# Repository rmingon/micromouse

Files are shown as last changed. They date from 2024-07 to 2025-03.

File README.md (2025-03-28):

# MICRO MOUSE Project

ir test (https://www.youtube.com/watch?v=sAMVhm9rnp0)

roll test (https://www.youtube.com/watch?v=oE-b8426ebo)

### 3d view

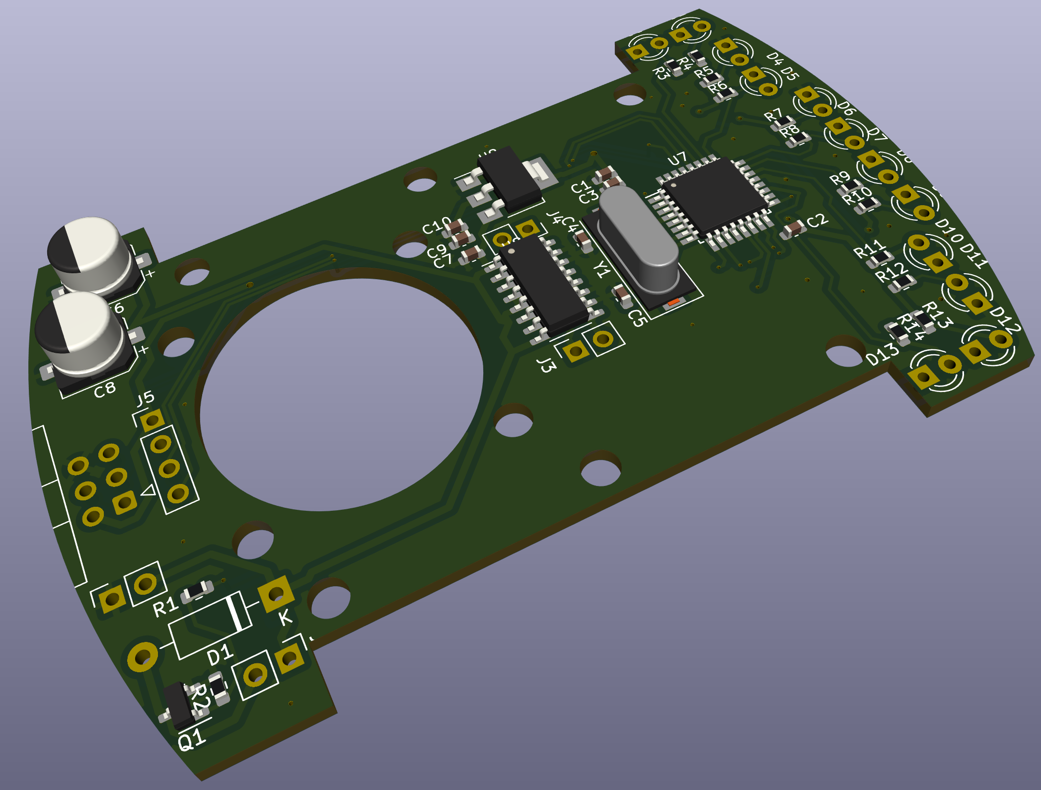
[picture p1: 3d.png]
'3d'


### pcb view

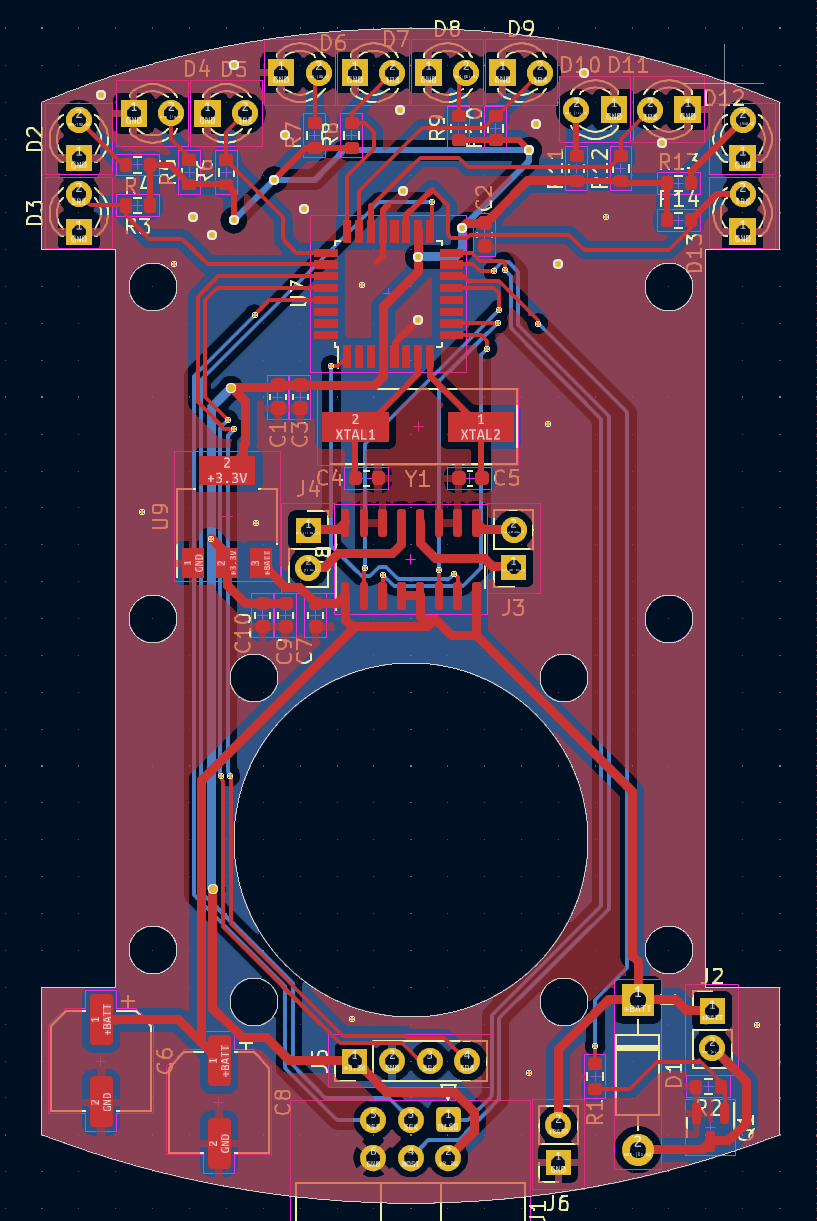
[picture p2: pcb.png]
'pcb'


### schematic view

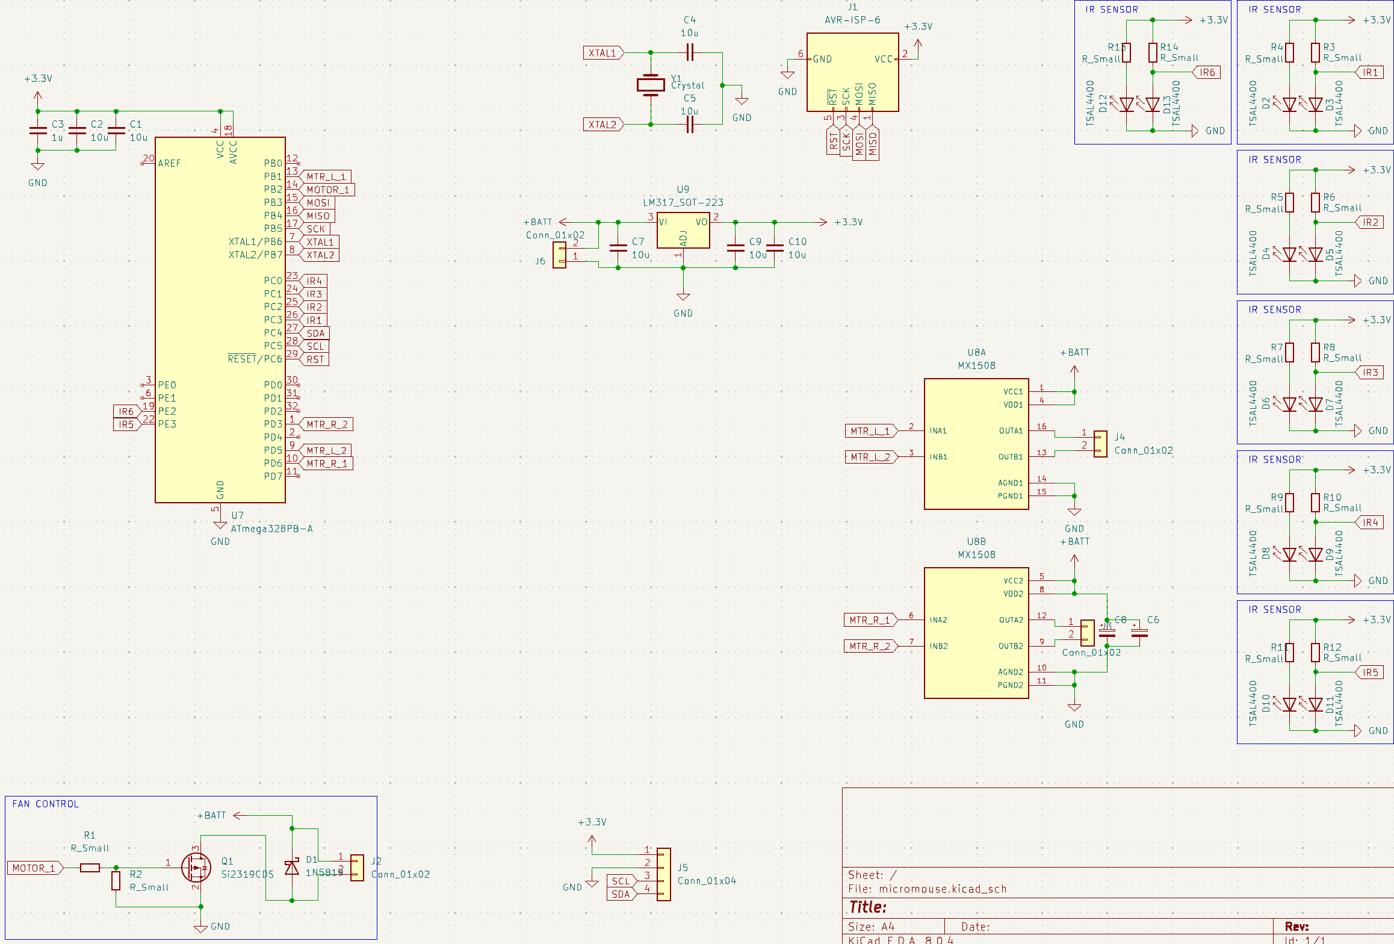
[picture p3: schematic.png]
'schematic'


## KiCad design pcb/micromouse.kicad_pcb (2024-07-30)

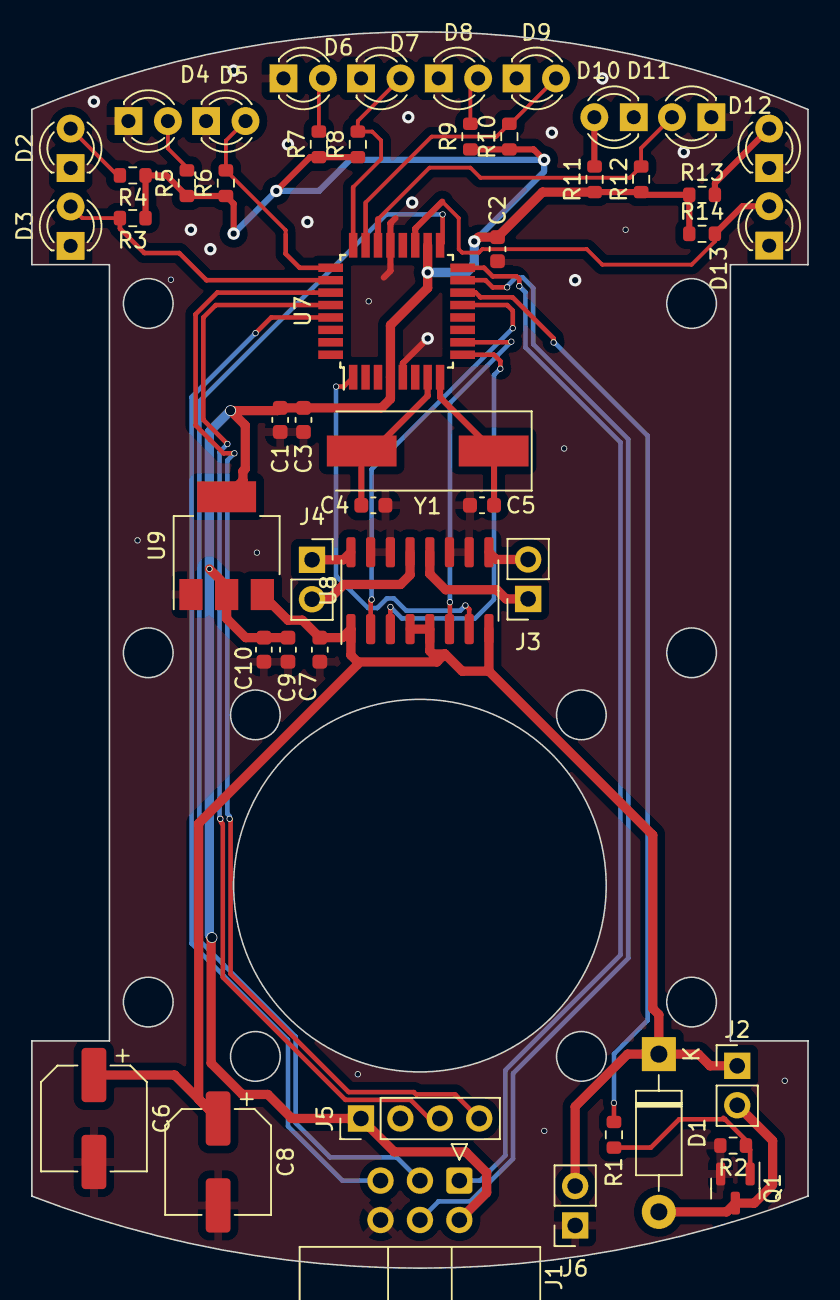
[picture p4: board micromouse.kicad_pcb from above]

Board: 2 copper layers, 50.0 x 79.6 mm, 48 parts (0 on the bottom side), 34 nets.

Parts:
C1, C2, C4, C5, C7, C9, C10: 10u; C_0603_1608Metric
C3: 1u; C_0603_1608Metric
C6, C8: C_Polarized_Small; CP_Elec_6.3x4.9
D1: 1N5819; D_DO-41_SOD81_P10.16mm_Horizontal
D2, D3, D4, D5, D6, D7, D8, D9, D10, D11, D12, D13: TSAL4400; LED_D3.0mm_IRBlack
J1: AVR-ISP-6; IDC-Header_2x03_P2.54mm_Horizontal
J2: Conn_01x02; PinHeader_1x02_P2.54mm_Vertical
J3, J4, J6: Conn_01x02; PinSocket_1x02_P2.54mm_Vertical
J5: Conn_01x04; PinHeader_1x04_P2.54mm_Vertical
Q1: Si2319CDS; SOT-23
R1, R2, R3, R4, R5, R6, R7, R8, R9, R10, R11, R12, R13, R14: R_Small; R_0603_1608Metric
U7: ATmega328PB-A; TQFP-32_7x7mm_P0.8mm
U8: MX1508; SOIC-16_3.9x9.9mm_P1.27mm
U9: LM317_SOT-223; SOT-223-3_TabPin2
Y1: Crystal; Crystal_SMD_HC49-SD

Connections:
+3.3V: C1.1, C2.1, C3.1, C9.1, C10.1, J1.2 (VCC), J5.1, R3.1, R4.1, R5.1, R6.1, R7.1, R8.1, R9.1, R10.1, R11.1, R12.1, R13.1, R14.1, U7.4 (VCC), U7.18 (AVCC), U9.2 (VO)
+BATT: C6.1, C7.1, C8.1, D1.1 (K), J2.1, J6.2, U8.1 (VCC1), U8.4 (VDD1), U8.5 (VCC2), U8.8 (VDD2), U9.3 (VI)
GND: C1.2, C2.2, C3.2, C4.2, C5.2, C6.2, C7.2, C8.2, C9.2, C10.2, D2.1 (K), D3.1 (K), D4.1 (K), D5.1 (K), D6.1 (K), D7.1 (K), D8.1 (K), D9.1 (K), D10.1 (K), D11.1 (K), D12.1 (K), D13.1 (K), J1.6 (GND), J5.2, J6.1, Q1.2 (S), R2.2, U7.5 (GND), U7.21 (GND), U8.10 (AGND2), U8.11 (PGND2), U8.14 (AGND1), U8.15 (PGND1), U9.1 (ADJ)
IR1: D3.2 (A), R3.2, U7.26 (PC3)
IR2: D5.2 (A), R6.2, U7.25 (PC2)
IR3: D7.2 (A), R8.2, U7.24 (PC1)
IR4: D9.2 (A), R10.2, U7.23 (PC0)
IR5: D11.2 (A), R12.2, U7.22 (PE3)
IR6: D13.2 (A), R14.2, U7.19 (PE2)
MISO: J1.1 (MISO), U7.16 (PB4)
MOSI: J1.4 (MOSI), U7.15 (PB3)
MOTOR_1: R1.1, U7.14 (PB2)
MTR_L_1: U7.13 (PB1), U8.2 (INA1)
MTR_L_2: U7.9 (PD5), U8.3 (INB1)
MTR_R_1: U7.10 (PD6), U8.6 (INA2)
MTR_R_2: U7.1 (PD3), U8.7 (INB2)
unnamed: D1.2 (A), J2.2, Q1.3 (D)
unnamed: D2.2 (A), R4.2
unnamed: D4.2 (A), R5.2
unnamed: D6.2 (A), R7.2
unnamed: D8.2 (A), R9.2
unnamed: D10.2 (A), R11.2
unnamed: D12.2 (A), R13.2
unnamed: J3.1, U8.12 (OUTA2)
unnamed: J3.2, U8.9 (OUTB2)
unnamed: J4.1, U8.16 (OUTA1)
unnamed: J4.2, U8.13 (OUTB1)
unnamed: Q1.1 (G), R1.2, R2.1
RST: J1.5 (~RST), U7.29 (~RESET/PC6)
SCK: J1.3 (SCK), U7.17 (PB5)
SCL: J5.3, U7.28 (PC5)
SDA: J5.4, U7.27 (PC4)
XTAL1: C4.1, U7.7 (XTAL1/PB6), Y1.2
XTAL2: C5.1, U7.8 (XTAL2/PB7), Y1.1

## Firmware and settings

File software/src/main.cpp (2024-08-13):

#include <Arduino.h>
#include <Wire.h>
#include <Adafruit_GFX.h>
#include <Adafruit_SH1106.h>

Adafruit_SH1106 display(0); 

const int ir1 = PINC3;
const int ir2 = PINC2;
const int ir3 = PINC1;
const int ir4 = PINC0;
const int ir5 = PIN_A7;
const int ir6 = PIN_A6;

void setup() {
  Serial.begin(115200);

  pinMode(ir1, INPUT);
  pinMode(ir2, INPUT);
  pinMode(ir3, INPUT);
  pinMode(ir4, INPUT);
  pinMode(ir5, INPUT);
  pinMode(ir6, INPUT);
  
  display.begin();
  display.clearDisplay(); 

}

void loop() {
  display.clearDisplay();

  display.setTextColor(WHITE);
  display.setTextSize(1); 
  
  display.setCursor(0, 50);
  display.println(analogRead(ir1));
  
  display.setCursor(0, 30);
  display.println(analogRead(ir2));
  
  display.setCursor(30, 10);
  display.println(analogRead(ir3));

  display.setCursor(80, 10);
  display.println(analogRead(ir4));
  
  display.setCursor(100, 30);
  display.println(analogRead(ir5));
  
  display.setCursor(100, 50);
  display.println(analogRead(ir6));

  display.display();

  delay(200);
  
}

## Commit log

2024-07-01 add ir sensor
    [micromouse.kicad_sch]
2024-07-01 add mcu
    [micromouse.kicad_sch]
2024-07-01 add program port
    [micromouse.kicad_sch]
2024-07-01 wiring mcu program port
    [micromouse.kicad_sch]
2024-07-01 add motor control
    [micromouse.kicad_sch]
2024-07-01 wiring mcu
    [micromouse.kicad_pcb, micromouse.kicad_sch]
2024-07-02 add fan control
    [micromouse.kicad_sch]
2024-07-02 add motor + fan
    [micromouse.kicad_sch]
2024-07-02 add IR 3d + pin i2c screen
    [micromouse.kicad_pcb, micromouse.kicad_sch]
2024-07-02 remake IR wiring
    [micromouse.kicad_pcb, micromouse.kicad_sch]
2024-07-02 update link
    [micromouse.kicad_pcb, micromouse.kicad_sch]
2024-07-10 update output
    [micromouse.kicad_pcb]
2024-07-29 update ir sensor
    [micromouse.kicad_sch]
2024-07-29 leds placed
    [micromouse.kicad_pcb]
2024-07-29 leds resistor placed
    [micromouse.kicad_pcb]
2024-07-29 finish wiring
    [micromouse.kicad_pcb]
2024-07-30 update plot settings
    [micromouse.kicad_pcb]
